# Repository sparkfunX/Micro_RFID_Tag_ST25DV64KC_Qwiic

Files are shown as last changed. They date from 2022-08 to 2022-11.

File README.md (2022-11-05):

# SparkX Micro Dynamic NFC/RFID Tag - ST25DV64KC

<p align="center">
    <a href="https://github.com/sparkfunX/Qwiic_RFID_Tag/blob/master/LICENSE" alt="License">
        </a>
    <a href="https://twitter.com/intent/follow?screen_name=sparkfun">
                    </a>
</p>

<table class="table table-hover table-striped table-bordered">
    <tr align="center">
     <td></td>
    </tr>
    <tr align="center">
        <td><a href="https://www.sparkfun.com/products/20691">SparkX Micro Dynamic RFID Tag - ST25DV64KC (SPX-20691)</a></td>
    </tr>
</table>

The STMicroelectronics ST25DV _**dynamic**_ Near Frequency Communication / Radio Frequency Identification tag ICs are awesome! The ST25DV64KC offers 64-kBit (8-kBytes) of EEPROM memory which can be accessed over both I2C and RF (NFC)! It's a state-of-the-art tag which conforms to ISO/IEC 15693 or NFC Forum Type 5 recommendations. You can read and write the tag's memory using NFC even while the tag is powered down or disconnected!

The EEPROM memory can be divided into four areas, each of which can have different levels of protection applied. Want to store your data so everyone has read and write access over both I2C and RF? You can do that.
In fact, that's the default! Want to store your data in an area which can only be read if you know the password, and cannot be written to (via RF)? You can do that too!

Our [Arduino Library](https://github.com/sparkfun/SparkFun_ST25DV64KC_Arduino_Library) provides all of the methods you need to read and write the user memory, control the read and write permissions, alter the area sizes and apply password control. Not only that! We've included extra methods which will let you read and write **NDEF (NFC Forum Data Exchange Format) URI, WiFi and Text records** which your smart phone can understand!

Do you want your project to be able to log up to 8-kBytes of data (via I2C) and then be able to read it using your smart phone - even if your project is powered off? Our library lets you do that!

Do you want to be able to write WiFi credentials (SSID and Password) into tag memory using your smart phone and then to be able to read them over I2C so your Arduino board can join the network? With our library you can do that too!

Do you want to be able to manufacture and test your product and then program it with keys or other credentials just before you ship? We've got you covered.

Are you developing equipment or appliances for the home? Would you like to store diagnostic information so that the repair engineer can access it using their smart phone? Our library lets you do that! Would you like the customer to be able to read the diagnostics with _their_ smart phone and then email them to you? Our library will let you do that too! (Apart from the email bit - obvs.. You will need to add that bit yourself.)

Are you designing a poster for your project? Do you want to be able to program your tag using Arduino and then stick it to your poster so people can interact with it? Hey, we've got you covered there too!

## Arduino Library Documentation

A full library use overview, API reference guide and key example walk-throughs are available on GitHub Pages - [sparkfun.github.io/SparkFun_ST25DV64KC_Arduino_Library](https://sparkfun.github.io/SparkFun_ST25DV64KC_Arduino_Library/)

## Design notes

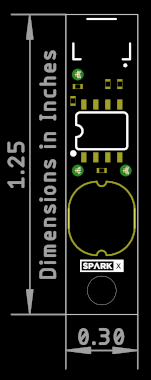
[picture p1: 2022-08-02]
Hardware/Dimensions.png

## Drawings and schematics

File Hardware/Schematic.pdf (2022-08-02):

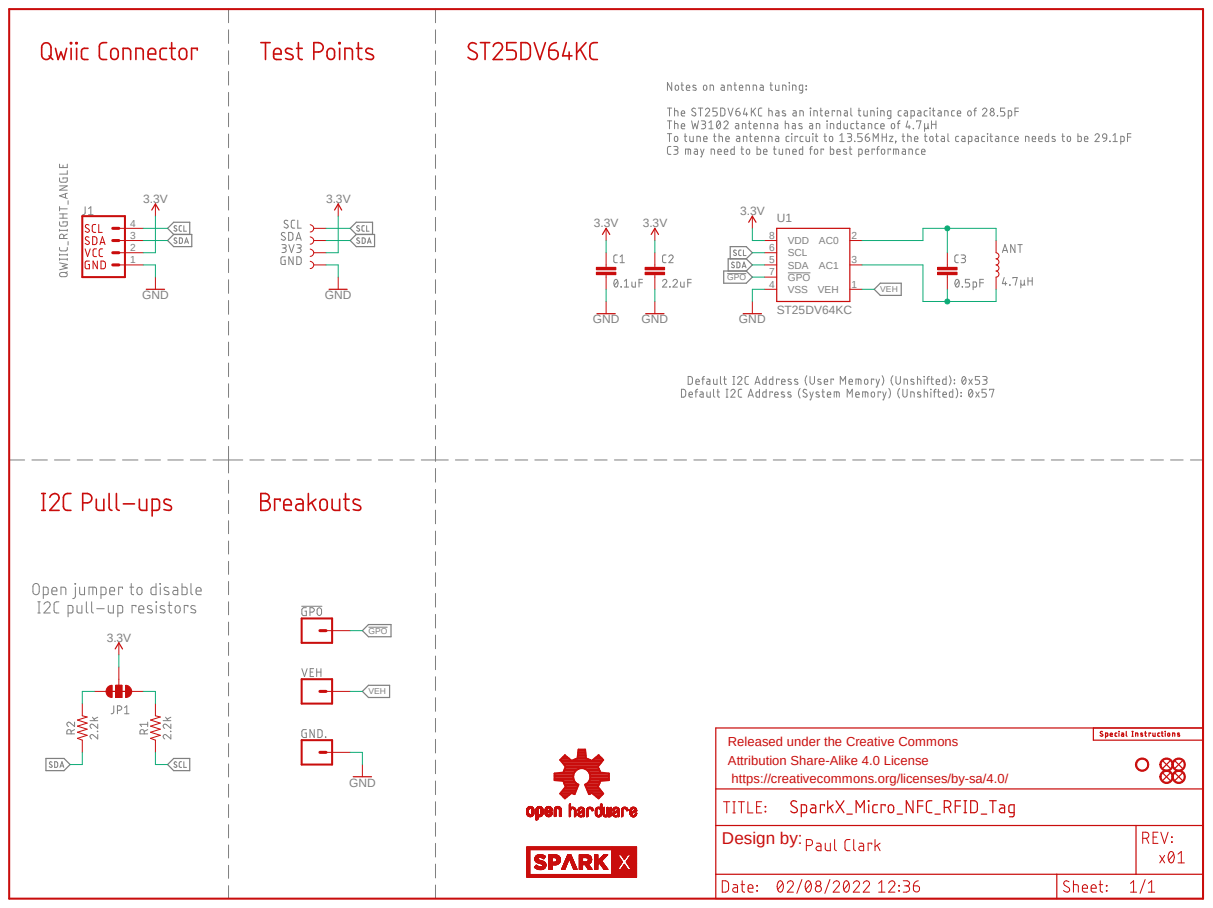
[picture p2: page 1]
GND; VDD 8 SCL 6 SDA 5 GPO 7; VSS 4; VEH 1; GPO; VEH; Released under the Creative Commons; Design by:

Attribution Share-Alike 4.0 License
https://creativecommons.org/licenses/by-sa/4.0/

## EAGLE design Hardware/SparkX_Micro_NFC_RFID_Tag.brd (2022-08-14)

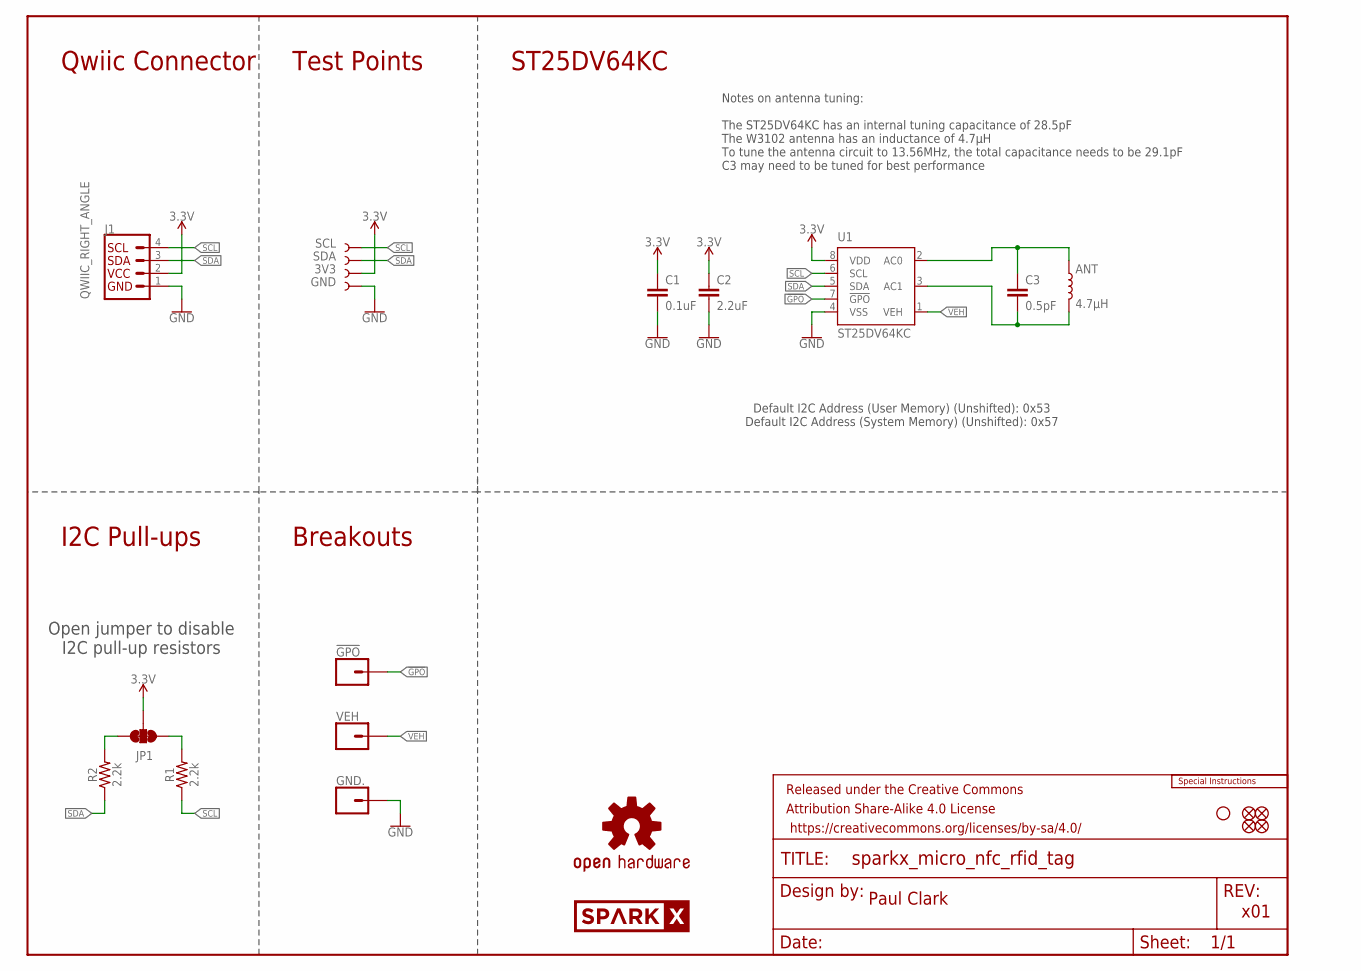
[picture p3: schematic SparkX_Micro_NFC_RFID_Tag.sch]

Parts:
3V3: TEST-POINT3; PAD.03X.03
!GPO!: CONN_01_1MM; 1X01_1MM_NO_SILK
ANT: 4.7μH; W3102
C1: 0.1uF; 0402-TIGHT
C2: 2.2uF; 0402-TIGHT
C3: 0.5pF; 0402-TIGHT
FD1, FD2, FD3, FD4: FIDUCIALUFIDUCIAL; FIDUCIAL-MICRO
FRAME2: FRAME-LETTER; CREATIVE_COMMONS
GND: TEST-POINT3; PAD.03X.03
GND.: CONN_01_1MM; 1X01_1MM_NO_SILK
H1: STAND-OFFTIGHT; STAND-OFF-TIGHT
J1: QWIIC_RIGHT_ANGLE; JST04_1MM_RA
JP1: JUMPER-SMT_3_2-NC_TRACE_SILK; SMT-JUMPER_3_2-NC_TRACE_SILK
LOGO1: SPECIAL_INSTRUCTIONS-ORDERING; ORDERING_INSTRUCTIONS
LOGO2: OSHW-LOGOMINI; OSHW-LOGO-MINI
R1, R2: 2.2k; 0402-TIGHT
SCL: TEST-POINT3; PAD.03X.03
SDA: TEST-POINT3; PAD.03X.03
U1: ST25DV64KC; SO08
U$1: SPARKX-LOGO2; SPARKX-TINY
VEH: CONN_01_1MM; 1X01_1MM_NO_SILK

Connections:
3.3V: 3V3.1, C1.1, C2.1, J1.2, JP1.2, U1.8 (VDD)
!GPO!: !GPO!.1, U1.7 (!GPO!)
GND: C1.2, C2.2, GND.1, GND..1, J1.1, U1.4 (VSS)
unnamed: ANT.2, C3.2, U1.3 (AC1)
unnamed: ANT.1, C3.1, U1.2 (AC0)
unnamed: JP1.3, R2.2
unnamed: JP1.1, R1.2
SCL: J1.4, R1.1, SCL.1, U1.6 (SCL)
SDA: J1.3, R2.1, SDA.1, U1.5 (SDA)
VEH: U1.1 (VEH), VEH.1

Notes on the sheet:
Paul Clark
x01
Qwiic Connector
ST25DV64KC
Default I2C Address (User Memory) (Unshifted): 0x53 Default I2C Address (System Memory) (Unshifted): 0x57
Notes on antenna tuning: The ST25DV64KC has an internal tuning capacitance of 28.5pF The W3102 antenna has an inductance of 4.7µH To tune the antenna circuit to 13.56MHz, the total capacitance needs to be 29.1pF C3 may need to be tuned for best performance
Open jumper to disable I2C pull-up resistors
I2C Pull-ups
Test Points
Breakouts

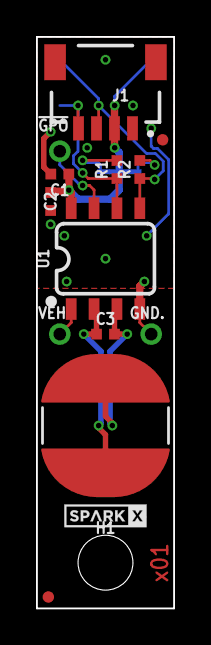
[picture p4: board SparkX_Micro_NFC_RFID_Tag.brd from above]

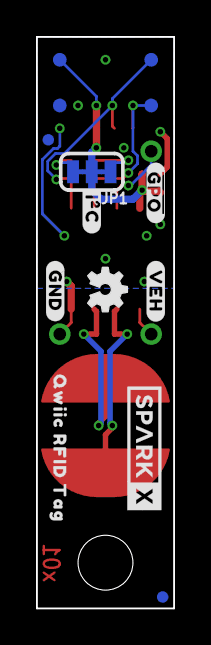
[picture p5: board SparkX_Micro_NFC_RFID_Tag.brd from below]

Board: 2 copper layers, 7.6 x 31.8 mm, 31 parts (14 on the bottom side), 10 nets.

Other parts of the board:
U$2: ##GPO##0
U$3: QWIIC_RFID_TAG0
U$4: #VEH#0
U$5: #I�C#0
U$6: #GND#0
U$20: SPARKX-LOGO3; SPARKX-SMALL

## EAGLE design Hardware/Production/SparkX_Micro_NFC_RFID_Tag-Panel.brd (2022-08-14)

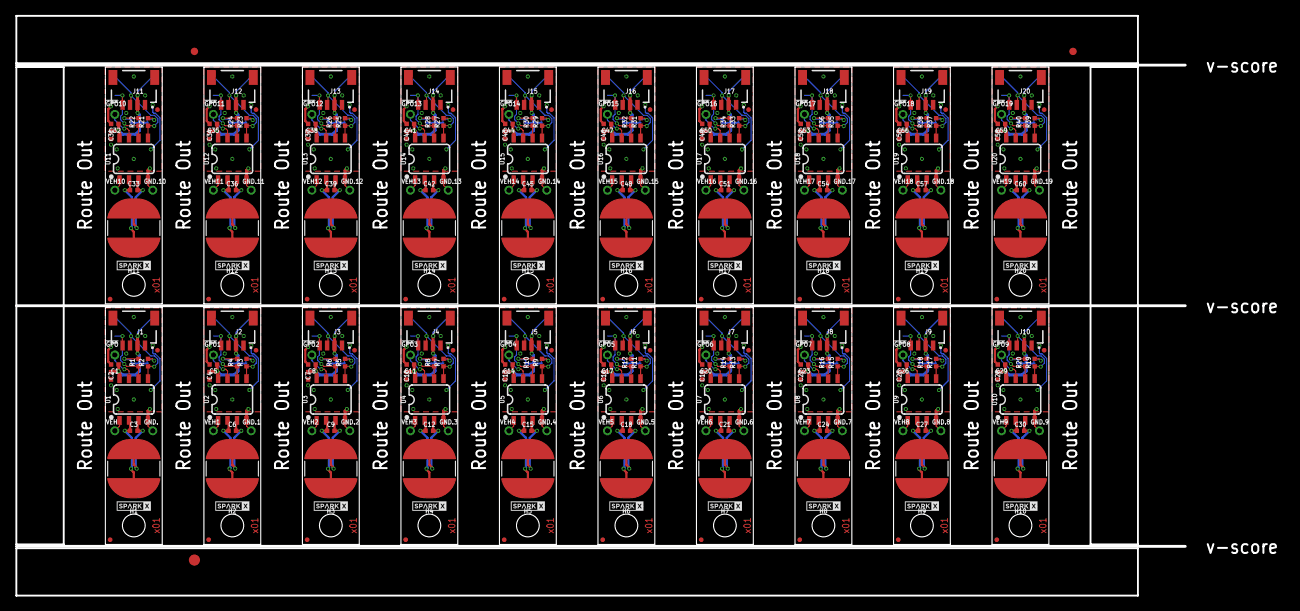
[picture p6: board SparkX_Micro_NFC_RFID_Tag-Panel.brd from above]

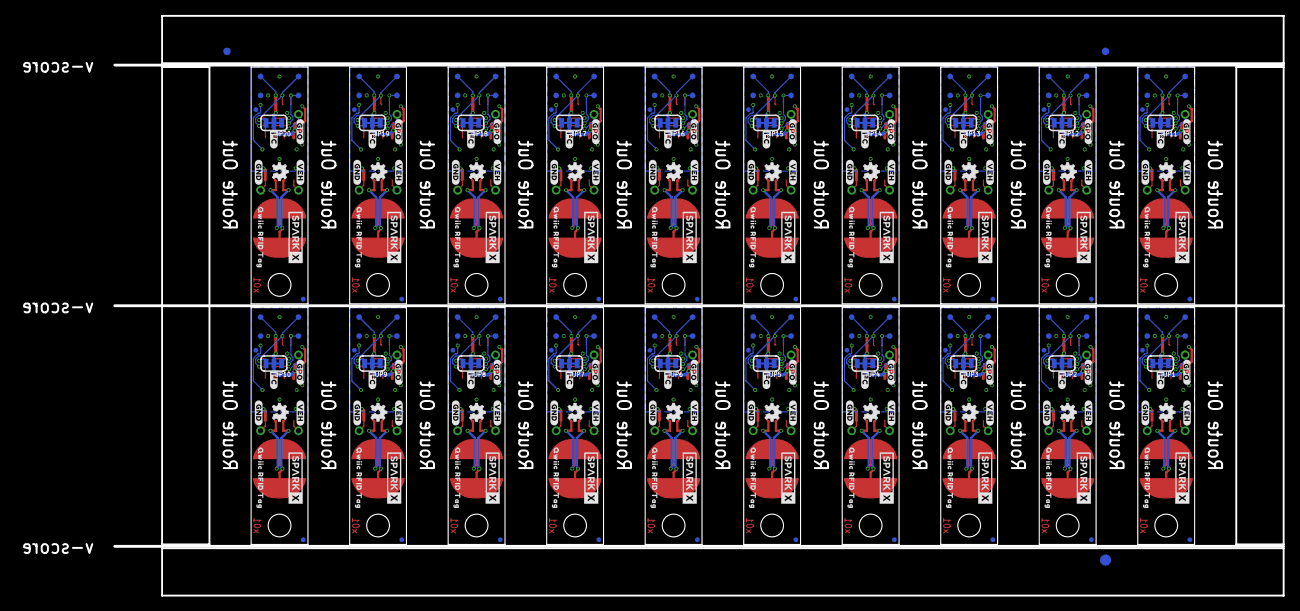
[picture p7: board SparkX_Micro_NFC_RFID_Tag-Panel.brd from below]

Board: 2 copper layers, 156.7 x 77.7 mm, 586 parts (283 on the bottom side), 200 nets.

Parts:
3V1, 3V2, 3V3, 3V4, 3V5, 3V6, 3V7, 3V8, 3V9, 3V10, 3V11, 3V12, 3V13, 3V14, 3V15, 3V16, 3V17, 3V18, 3V19, 3V20: TEST-POINT3; PAD.03X.03
!GPO!, !GPO!1, !GPO!2, !GPO!3, !GPO!4, !GPO!5, !GPO!6, !GPO!7, !GPO!8, !GPO!9, !GPO!10, !GPO!11, !GPO!12, !GPO!13, !GPO!14, !GPO!15, !GPO!16, !GPO!17, !GPO!18, !GPO!19: 1X01_1MM_NO_SILK
ANT, ANT1, ANT2, ANT3, ANT4, ANT5, ANT6, ANT7, ANT8, ANT9, ANT10, ANT11, ANT12, ANT13, ANT14, ANT15, ANT16, ANT17, ANT18, ANT19: 4.7μH; W3102
C1, C5, C8, C11, C14, C17, C20, C23, C26, C29, C32, C35, C38, C41, C44, C47, C50, C53, C56, C59: 0.1uF; 0402-TIGHT
C2, C4, C7, C10, C13, C16, C19, C22, C25, C28, C31, C34, C37, C40, C43, C46, C49, C52, C55, C58: 2.2uF; 0402-TIGHT
C3, C6, C9, C12, C15, C18, C21, C24, C27, C30, C33, C36, C39, C42, C45, C48, C51, C54, C57, C60: 0.5pF; 0402-TIGHT
E$1, E$2, E$3, E$4: FIDUCIAL-1X2
E$5, E$6: FIDUCIAL-1.5X3
FD1, FD2, FD3, FD4, FD5, FD6, FD7, FD8, FD9, FD10, FD11, FD12, FD13, FD14, FD15, FD16, FD17, FD18, FD19, FD20, FD21, FD22, FD23, FD24, FD25, FD26, FD27, FD28, FD29, FD30, FD31, FD32, FD33, FD34, FD35, FD36, FD37, FD38, FD39, FD40, FD41, FD42, FD43, FD44, FD45, FD46, FD47, FD48, FD49, FD50, FD51, FD52, FD53, FD54, FD55, FD56, FD57, FD58, FD59, FD60, FD61, FD62, FD63, FD64, FD65, FD66, FD67, FD68, FD69, FD70, FD71, FD72, FD73, FD74, FD75, FD76, FD77, FD78, FD79, FD80: FIDUCIALUFIDUCIAL; FIDUCIAL-MICRO
GND, GND1, GND2, GND3, GND4, GND5, GND6, GND7, GND8, GND9, GND10, GND11, GND12, GND13, GND14, GND15, GND16, GND17, GND18, GND19: TEST-POINT3; PAD.03X.03
GND., GND.1, GND.2, GND.3, GND.4, GND.5, GND.6, GND.7, GND.8, GND.9, GND.10, GND.11, GND.12, GND.13, GND.14, GND.15, GND.16, GND.17, GND.18, GND.19: 1X01_1MM_NO_SILK
H1, H2, H3, H4, H5, H6, H7, H8, H9, H10, H11, H12, H13, H14, H15, H16, H17, H18, H19, H20: STAND-OFFTIGHT; STAND-OFF-TIGHT
J1, J2, J3, J4, J5, J6, J7, J8, J9, J10, J11, J12, J13, J14, J15, J16, J17, J18, J19, J20: QWIIC_RIGHT_ANGLE; JST04_1MM_RA
JP1, JP2, JP3, JP4, JP5, JP6, JP7, JP8, JP9, JP10, JP11, JP12, JP13, JP14, JP15, JP16, JP17, JP18, JP19, JP20: JUMPER-SMT_3_2-NC_TRACE_SILK; SMT-JUMPER_3_2-NC_TRACE_SILK
LOGO1, LOGO2, LOGO3, LOGO4, LOGO5, LOGO6, LOGO7, LOGO8, LOGO9, LOGO10, LOGO11, LOGO12, LOGO13, LOGO14, LOGO15, LOGO16, LOGO17, LOGO18, LOGO19, LOGO20: OSHW-LOGOMINI; OSHW-LOGO-MINI
R1, R2, R3, R4, R5, R6, R7, R8, R9, R10, R11, R12, R13, R14, R15, R16, R17, R18, R19, R20, R21, R22, R23, R24, R25, R26, R27, R28, R29, R30, R31, R32, R33, R34, R35, R36, R37, R38, R39, R40: 2.2k; 0402-TIGHT
SCL, SCL1, SCL2, SCL3, SCL4, SCL5, SCL6, SCL7, SCL8, SCL9, SCL10, SCL11, SCL12, SCL13, SCL14, SCL15, SCL16, SCL17, SCL18, SCL19: TEST-POINT3; PAD.03X.03
SDA, SDA1, SDA2, SDA3, SDA4, SDA5, SDA6, SDA7, SDA8, SDA9, SDA10, SDA11, SDA12, SDA13, SDA14, SDA15, SDA16, SDA17, SDA18, SDA19: TEST-POINT3; PAD.03X.03
U1, U2, U3, U4, U5, U6, U7, U8, U9, U10, U11, U12, U13, U14, U15, U16, U17, U18, U19, U20: ST25DV64KC; SO08
U$1, U$7, U$14, U$22, U$29, U$36, U$43, U$50, U$57, U$64, U$71, U$78, U$85, U$92, U$99, U$106, U$113, U$120, U$127, U$134: SPARKX-LOGO2; SPARKX-TINY
U$2, U$10, U$17, U$25, U$32, U$39, U$46, U$53, U$60, U$67, U$74, U$81, U$88, U$95, U$102, U$109, U$116, U$123, U$130, U$137: ##GPO##0
U$3, U$13, U$21, U$28, U$35, U$42, U$49, U$56, U$63, U$70, U$77, U$84, U$91, U$98, U$105, U$112, U$119, U$126, U$133, U$140: QWIIC_RFID_TAG0
U$4, U$11, U$18, U$26, U$33, U$40, U$47, U$54, U$61, U$68, U$75, U$82, U$89, U$96, U$103, U$110, U$117, U$124, U$131, U$138: #VEH#0
U$5, U$9, U$16, U$24, U$31, U$38, U$45, U$52, U$59, U$66, U$73, U$80, U$87, U$94, U$101, U$108, U$115, U$122, U$129, U$136: #I�C#0
U$6, U$12, U$19, U$27, U$34, U$41, U$48, U$55, U$62, U$69, U$76, U$83, U$90, U$97, U$104, U$111, U$118, U$125, U$132, U$139: #GND#0
U$8, U$15, U$20, U$23, U$30, U$37, U$44, U$51, U$58, U$65, U$72, U$79, U$86, U$93, U$100, U$107, U$114, U$121, U$128, U$135: SPARKX-LOGO3; SPARKX-SMALL
VEH, VEH1, VEH2, VEH3, VEH4, VEH5, VEH6, VEH7, VEH8, VEH9, VEH10, VEH11, VEH12, VEH13, VEH14, VEH15, VEH16, VEH17, VEH18, VEH19: 1X01_1MM_NO_SILK

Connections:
3.3V: 3V3.1, C1.1, C2.1, J1.2, JP1.2, U1.8
3.3V1: 3V1.1, C4.1, C5.1, J2.2, JP2.2, U2.8
3.3V2: 3V2.1, C7.1, C8.1, J3.2, JP3.2, U3.8
3.3V3: 3V4.1, C10.1, C11.1, J4.2, JP4.2, U4.8
3.3V4: 3V5.1, C13.1, C14.1, J5.2, JP5.2, U5.8
3.3V5: 3V6.1, C16.1, C17.1, J6.2, JP6.2, U6.8
3.3V6: 3V7.1, C19.1, C20.1, J7.2, JP7.2, U7.8
3.3V7: 3V8.1, C22.1, C23.1, J8.2, JP8.2, U8.8
3.3V8: 3V9.1, C25.1, C26.1, J9.2, JP9.2, U9.8
3.3V9: 3V10.1, C28.1, C29.1, J10.2, JP10.2, U10.8
3.3V10: 3V11.1, C31.1, C32.1, J11.2, JP11.2, U11.8
3.3V11: 3V12.1, C34.1, C35.1, J12.2, JP12.2, U12.8
3.3V12: 3V13.1, C37.1, C38.1, J13.2, JP13.2, U13.8
3.3V13: 3V14.1, C40.1, C41.1, J14.2, JP14.2, U14.8
3.3V14: 3V15.1, C43.1, C44.1, J15.2, JP15.2, U15.8
3.3V15: 3V16.1, C46.1, C47.1, J16.2, JP16.2, U16.8
3.3V16: 3V17.1, C49.1, C50.1, J17.2, JP17.2, U17.8
3.3V17: 3V18.1, C52.1, C53.1, J18.2, JP18.2, U18.8
3.3V18: 3V19.1, C55.1, C56.1, J19.2, JP19.2, U19.8
3.3V19: 3V20.1, C58.1, C59.1, J20.2, JP20.2, U20.8
!GPO!: !GPO!.1, U1.7
!GPO!1: !GPO!1.1, U2.7
!GPO!2: !GPO!2.1, U3.7
!GPO!3: !GPO!3.1, U4.7
!GPO!4: !GPO!4.1, U5.7
!GPO!5: !GPO!5.1, U6.7
!GPO!6: !GPO!6.1, U7.7
!GPO!7: !GPO!7.1, U8.7
!GPO!8: !GPO!8.1, U9.7
!GPO!9: !GPO!9.1, U10.7
!GPO!10: !GPO!10.1, U11.7
!GPO!11: !GPO!11.1, U12.7
!GPO!12: !GPO!12.1, U13.7
!GPO!13: !GPO!13.1, U14.7
!GPO!14: !GPO!14.1, U15.7
!GPO!15: !GPO!15.1, U16.7
!GPO!16: !GPO!16.1, U17.7
!GPO!17: !GPO!17.1, U18.7
!GPO!18: !GPO!18.1, U19.7
!GPO!19: !GPO!19.1, U20.7
GND: C1.2, C2.2, GND.1, GND..1, J1.1, U1.4
GND1: C4.2, C5.2, GND1.1, GND.1.1, J2.1, U2.4
GND2: C7.2, C8.2, GND2.1, GND.2.1, J3.1, U3.4
GND3: C10.2, C11.2, GND3.1, GND.3.1, J4.1, U4.4
GND4: C13.2, C14.2, GND4.1, GND.4.1, J5.1, U5.4
GND5: C16.2, C17.2, GND5.1, GND.5.1, J6.1, U6.4
GND6: C19.2, C20.2, GND6.1, GND.6.1, J7.1, U7.4
GND7: C22.2, C23.2, GND7.1, GND.7.1, J8.1, U8.4
GND8: C25.2, C26.2, GND8.1, GND.8.1, J9.1, U9.4
GND9: C28.2, C29.2, GND9.1, GND.9.1, J10.1, U10.4
GND10: C31.2, C32.2, GND10.1, GND.10.1, J11.1, U11.4
GND11: C34.2, C35.2, GND11.1, GND.11.1, J12.1, U12.4
GND12: C37.2, C38.2, GND12.1, GND.12.1, J13.1, U13.4
GND13: C40.2, C41.2, GND13.1, GND.13.1, J14.1, U14.4
GND14: C43.2, C44.2, GND14.1, GND.14.1, J15.1, U15.4
GND15: C46.2, C47.2, GND15.1, GND.15.1, J16.1, U16.4
GND16: C49.2, C50.2, GND16.1, GND.16.1, J17.1, U17.4
GND17: C52.2, C53.2, GND17.1, GND.17.1, J18.1, U18.4
GND18: C55.2, C56.2, GND18.1, GND.18.1, J19.1, U19.4
GND19: C58.2, C59.2, GND19.1, GND.19.1, J20.1, U20.4
unnamed: ANT.2, C3.2, U1.3
unnamed: ANT.1, C3.1, U1.2
unnamed: JP1.3, R2.2
unnamed: JP1.1, R1.2
unnamed: ANT1.2, C6.2, U2.3
unnamed: ANT1.1, C6.1, U2.2
unnamed: JP2.3, R3.2
unnamed: JP2.1, R4.2
unnamed: ANT2.2, C9.2, U3.3
unnamed: ANT2.1, C9.1, U3.2
unnamed: JP3.3, R5.2
unnamed: JP3.1, R6.2
unnamed: ANT3.2, C12.2, U4.3
unnamed: ANT3.1, C12.1, U4.2
unnamed: JP4.3, R7.2
unnamed: JP4.1, R8.2
unnamed: ANT4.2, C15.2, U5.3
unnamed: ANT4.1, C15.1, U5.2
unnamed: JP5.3, R9.2
unnamed: JP5.1, R10.2
unnamed: ANT5.2, C18.2, U6.3
unnamed: ANT5.1, C18.1, U6.2
unnamed: JP6.3, R11.2
unnamed: JP6.1, R12.2
unnamed: ANT6.2, C21.2, U7.3
unnamed: ANT6.1, C21.1, U7.2
unnamed: JP7.3, R13.2
unnamed: JP7.1, R14.2
unnamed: ANT7.2, C24.2, U8.3
unnamed: ANT7.1, C24.1, U8.2
unnamed: JP8.3, R15.2
unnamed: JP8.1, R16.2
unnamed: ANT8.2, C27.2, U9.3
unnamed: ANT8.1, C27.1, U9.2
unnamed: JP9.3, R17.2
unnamed: JP9.1, R18.2
unnamed: ANT9.2, C30.2, U10.3
unnamed: ANT9.1, C30.1, U10.2
unnamed: JP10.3, R19.2
unnamed: JP10.1, R20.2
unnamed: ANT10.2, C33.2, U11.3
unnamed: ANT10.1, C33.1, U11.2
unnamed: JP11.3, R21.2
unnamed: JP11.1, R22.2
unnamed: ANT11.2, C36.2, U12.3
unnamed: ANT11.1, C36.1, U12.2
unnamed: JP12.3, R23.2
unnamed: JP12.1, R24.2
unnamed: ANT12.2, C39.2, U13.3
unnamed: ANT12.1, C39.1, U13.2
unnamed: JP13.3, R25.2
unnamed: JP13.1, R26.2
unnamed: ANT13.2, C42.2, U14.3
unnamed: ANT13.1, C42.1, U14.2
unnamed: JP14.3, R27.2
unnamed: JP14.1, R28.2
unnamed: ANT14.2, C45.2, U15.3
unnamed: ANT14.1, C45.1, U15.2
unnamed: JP15.3, R29.2
unnamed: JP15.1, R30.2
unnamed: ANT15.2, C48.2, U16.3
unnamed: ANT15.1, C48.1, U16.2
unnamed: JP16.3, R31.2
unnamed: JP16.1, R32.2
unnamed: ANT16.2, C51.2, U17.3
unnamed: ANT16.1, C51.1, U17.2
unnamed: JP17.3, R33.2
unnamed: JP17.1, R34.2
unnamed: ANT17.2, C54.2, U18.3
unnamed: ANT17.1, C54.1, U18.2
unnamed: JP18.3, R35.2
unnamed: JP18.1, R36.2
unnamed: ANT18.2, C57.2, U19.3
unnamed: ANT18.1, C57.1, U19.2
unnamed: JP19.3, R37.2
unnamed: JP19.1, R38.2
unnamed: ANT19.2, C60.2, U20.3
unnamed: ANT19.1, C60.1, U20.2
unnamed: JP20.3, R39.2
unnamed: JP20.1, R40.2
SCL: J1.4, R1.1, SCL.1, U1.6
SCL1: J2.4, R4.1, SCL1.1, U2.6
SCL2: J3.4, R6.1, SCL2.1, U3.6
SCL3: J4.4, R8.1, SCL3.1, U4.6
SCL4: J5.4, R10.1, SCL4.1, U5.6
SCL5: J6.4, R12.1, SCL5.1, U6.6
SCL6: J7.4, R14.1, SCL6.1, U7.6
SCL7: J8.4, R16.1, SCL7.1, U8.6
SCL8: J9.4, R18.1, SCL8.1, U9.6
SCL9: J10.4, R20.1, SCL9.1, U10.6
SCL10: J11.4, R22.1, SCL10.1, U11.6
SCL11: J12.4, R24.1, SCL11.1, U12.6
SCL12: J13.4, R26.1, SCL12.1, U13.6
SCL13: J14.4, R28.1, SCL13.1, U14.6
SCL14: J15.4, R30.1, SCL14.1, U15.6
SCL15: J16.4, R32.1, SCL15.1, U16.6
SCL16: J17.4, R34.1, SCL16.1, U17.6
SCL17: J18.4, R36.1, SCL17.1, U18.6
SCL18: J19.4, R38.1, SCL18.1, U19.6
SCL19: J20.4, R40.1, SCL19.1, U20.6
SDA: J1.3, R2.1, SDA.1, U1.5
SDA1: J2.3, R3.1, SDA1.1, U2.5
SDA2: J3.3, R5.1, SDA2.1, U3.5
SDA3: J4.3, R7.1, SDA3.1, U4.5
SDA4: J5.3, R9.1, SDA4.1, U5.5
SDA5: J6.3, R11.1, SDA5.1, U6.5
SDA6: J7.3, R13.1, SDA6.1, U7.5
SDA7: J8.3, R15.1, SDA7.1, U8.5
SDA8: J9.3, R17.1, SDA8.1, U9.5
SDA9: J10.3, R19.1, SDA9.1, U10.5
SDA10: J11.3, R21.1, SDA10.1, U11.5
SDA11: J12.3, R23.1, SDA11.1, U12.5
SDA12: J13.3, R25.1, SDA12.1, U13.5
SDA13: J14.3, R27.1, SDA13.1, U14.5
SDA14: J15.3, R29.1, SDA14.1, U15.5
SDA15: J16.3, R31.1, SDA15.1, U16.5
SDA16: J17.3, R33.1, SDA16.1, U17.5
SDA17: J18.3, R35.1, SDA17.1, U18.5
SDA18: J19.3, R37.1, SDA18.1, U19.5
SDA19: J20.3, R39.1, SDA19.1, U20.5
VEH: U1.1, VEH.1
VEH1: U2.1, VEH1.1
VEH2: U3.1, VEH2.1
VEH3: U4.1, VEH3.1
VEH4: U5.1, VEH4.1
VEH5: U6.1, VEH5.1
VEH6: U7.1, VEH6.1
VEH7: U8.1, VEH7.1
VEH8: U9.1, VEH8.1
VEH9: U10.1, VEH9.1
VEH10: U11.1, VEH10.1
VEH11: U12.1, VEH11.1
VEH12: U13.1, VEH12.1
VEH13: U14.1, VEH13.1
VEH14: U15.1, VEH14.1
VEH15: U16.1, VEH15.1
VEH16: U17.1, VEH16.1
VEH17: U18.1, VEH17.1
VEH18: U19.1, VEH18.1
VEH19: U20.1, VEH19.1

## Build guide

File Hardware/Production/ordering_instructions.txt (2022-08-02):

panel size, 151x78mm
PCB thickness, 1.6mm
number of layers, 2
soldermask color, Black
silkscreen color, White
oz copper, 1oz
finish, HASL lead free
stencils, top+bottom
pcs per panel, 20
min trace width, 0.1524mm / 0.0060in
min drill size, 0.3000mm / 0.0118in

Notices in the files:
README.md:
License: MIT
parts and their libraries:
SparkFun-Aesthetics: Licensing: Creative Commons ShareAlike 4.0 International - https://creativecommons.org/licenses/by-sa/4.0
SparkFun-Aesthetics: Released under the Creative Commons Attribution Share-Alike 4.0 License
